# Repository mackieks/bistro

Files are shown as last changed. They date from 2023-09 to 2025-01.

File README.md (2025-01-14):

# bistro
Wii U regulator board. Runs a Wii U motherboard (no disc drive) from 1S lithium-ion. Licensed under Solderpad Hardware License v2.1. Have fun!

- x2 SiC431C 24A buck regulators for 1v and 1.15v (CPU + GPU)
- x2 MUN3CAD01-SB 1A bucks for 1.1V and 1.25V (for DRH)
- x1 MUN3CAD03-SE 3A buck for 1.5V (RAM)
- x1 TPS63810YFFR 2.5A buck-boost for 3.3V
- x1 FAN48610BUC50X 5V 1A boost (USB)

[Mouser project with BOM](https://www.mouser.com/ProjectManager/ProjectDetail.aspx?AccessID=d68b6111f5)

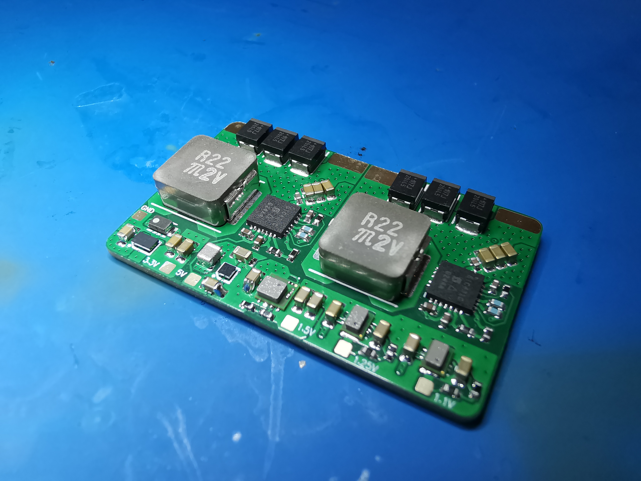
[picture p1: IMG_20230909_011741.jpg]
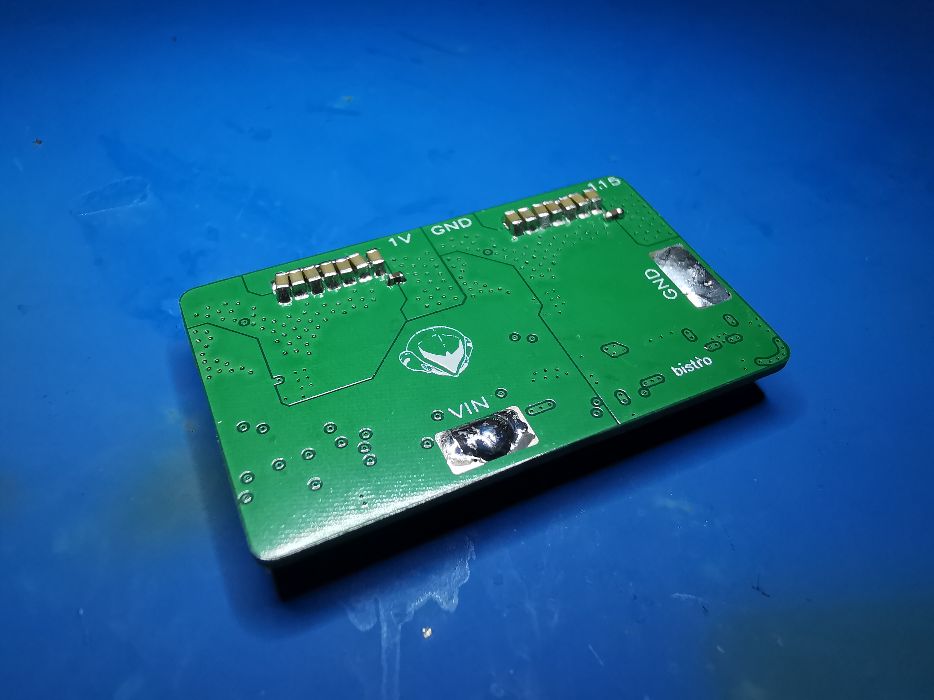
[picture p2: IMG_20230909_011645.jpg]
 


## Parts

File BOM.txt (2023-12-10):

Partlist

Exported from cafereg2.sch at 12/10/2023 4:18 PM

EAGLE Version 9.6.1 Copyright (c) 1988-2020 Autodesk, Inc.

Assembly variant: 

Part     Value                Device                   Package                 Library        Sheet

C1       22uF                 C-USC0603                C0603                   resistor       1
C2       22uF                 C-USC0603                C0603                   resistor       1
C3       22uF                 C-USC0603                C0603                   resistor       1
C4       0.1uF                C-USC0402                C0402                   resistor       1
C5       1uF                  C-USC0402                C0402                   resistor       1
C6       2.2uF                C-USC0402                C0402                   resistor       1
C7       0.1uF                C-USC0402                C0402                   resistor       1
C8       0.1uF                C-USC0402                C0402                   resistor       1
C9       22uF                 C-USC0603                C0603                   resistor       1
C10      22uF                 C-USC0603                C0603                   resistor       1
C11      22uF                 C-USC0603                C0603                   resistor       1
C12      22uF                 C-USC0603                C0603                   resistor       1
C13      22uF                 C-USC0603                C0603                   resistor       1
C14      22uF                 C-USC0603                C0603                   resistor       1
C15      22uF                 C-USC0603                C0603                   resistor       1
C16      0.1uF                C-USC0402                C0402                   resistor       1
C17      F930J107KBA          F930J107KBA              CAPPM3528X210N          SamacSys_Parts 1
C18      F930J107KBA          F930J107KBA              CAPPM3528X210N          SamacSys_Parts 1
C19      F930J107KBA          F930J107KBA              CAPPM3528X210N          SamacSys_Parts 1
C20      22uF                 C-USC0603                C0603                   resistor       2
C21      22uF                 C-USC0603                C0603                   resistor       2
C22      22uF                 C-USC0603                C0603                   resistor       2
C23      0.1uF                C-USC0402                C0402                   resistor       2
C24      1uF                  C-USC0402                C0402                   resistor       2
C25      2.2uF                C-USC0402                C0402                   resistor       2
C26      0.1uF                C-USC0402                C0402                   resistor       2
C27      0.1uF                C-USC0402                C0402                   resistor       2
C28      22uF                 C-USC0603                C0603                   resistor       2
C29      22uF                 C-USC0603                C0603                   resistor       2
C30      22uF                 C-USC0603                C0603                   resistor       2
C31      22uF                 C-USC0603                C0603                   resistor       2
C32      22uF                 C-USC0603                C0603                   resistor       2
C33      22uF                 C-USC0603                C0603                   resistor       2
C34      22uF                 C-USC0603                C0603                   resistor       2
C35      0.1uF                C-USC0402                C0402                   resistor       2
C36      F930J107KBA          F930J107KBA              CAPPM3528X210N          SamacSys_Parts 2
C37      F930J107KBA          F930J107KBA              CAPPM3528X210N          SamacSys_Parts 2
C38      F930J107KBA          F930J107KBA              CAPPM3528X210N          SamacSys_Parts 2
C39      22uF                 C-USC0603                C0603                   resistor       3
C40      22uF                 C-USC0603                C0603                   resistor       3
C41      22uF                 C-USC0603                C0603                   resistor       3
C42      22uF                 C-USC0603                C0603                   resistor       4
C43      22uF                 C-USC0603                C0603                   resistor       4
C44      22uF                 C-USC0603                C0603                   resistor       4
C45      22uF                 C-USC0603                C0603                   resistor       5
C46      22uF                 C-USC0603                C0603                   resistor       5
C47      22uF                 C-USC0603                C0603                   resistor       5
C48      22uF                 C-USC0603                C0603                   resistor       5
C49      22uF                 C-USC0603                C0603                   resistor       6
C50      22uF                 C-USC0603                C0603                   resistor       6
IC1      SiC431CED-T1-GE3     SiC431CED-T1-GE3         SiC431CED-T1-GE3        personal       1
IC2      SiC431CED-T1-GE3     SiC431CED-T1-GE3         SiC431CED-T1-GE3        personal       2
IC3      TPS63810YFFR         TPS63810YFFR             BGA15C40P3X5_134X226X62 SamacSys_Parts 3
IC4      MUN3CAD03-SE         MUN3CAD03-SE             MUN3CAD03SE             SamacSys_Parts 4
IC5      MUN3CAD01-SB         MUN3CAD01-SB             MUN3CAD01SB             SamacSys_Parts 5
IC6      MUN3CAD01-SB         MUN3CAD01-SB             MUN3CAD01SB             SamacSys_Parts 5
IC7      FAN48610BUC50X       FAN48610BUC50X           BGA9C40P3X3_122X122X62  SamacSys_Parts 6
L1       MPXV1D0840L1R0       MPXV1D0840L1R0           INDPM8680X400N          SamacSys_Parts 1
L2       MPXV1D0840L1R0       MPXV1D0840L1R0           INDPM8680X400N          SamacSys_Parts 2
L3       TFM201208BLE-R47MTCF L_CHIP-0805(2012-METRIC) INDC2009X120            Inductor       3
L4       1286AS-H-R47M=P2     1286AS-H-R47M=P2         1286ASH1R0MP2           SamacSys_Parts 6
R1       100k                 R-US_R0402               R0402                   resistor       1
R2       510k                 R-US_R0402               R0402                   resistor       1
R3       510k                 R-US_R0402               R0402                   resistor       1
R4       6.67k                R-US_R0402               R0402                   resistor       1
R5       10K                  R-US_R0402               R0402                   resistor       1
R6       100k                 R-US_R0402               R0402                   resistor       2
R7       510k                 R-US_R0402               R0402                   resistor       2
R8       510k                 R-US_R0402               R0402                   resistor       2
R9       11k                  R-US_R0402               R0402                   resistor       2
R10      12k                  R-US_R0402               R0402                   resistor       2
R11      200k                 R-US_R0402               R0402                   resistor       4
R12      133k                 R-US_R0402               R0402                   resistor       4
R13      200k                 R-US_R0402               R0402                   resistor       5
R14      187k                 R-US_R0402               R0402                   resistor       5
R15      187k                 R-US_R0402               R0402                   resistor       5
R16      200k                 R-US_R0402               R0402                   resistor       5

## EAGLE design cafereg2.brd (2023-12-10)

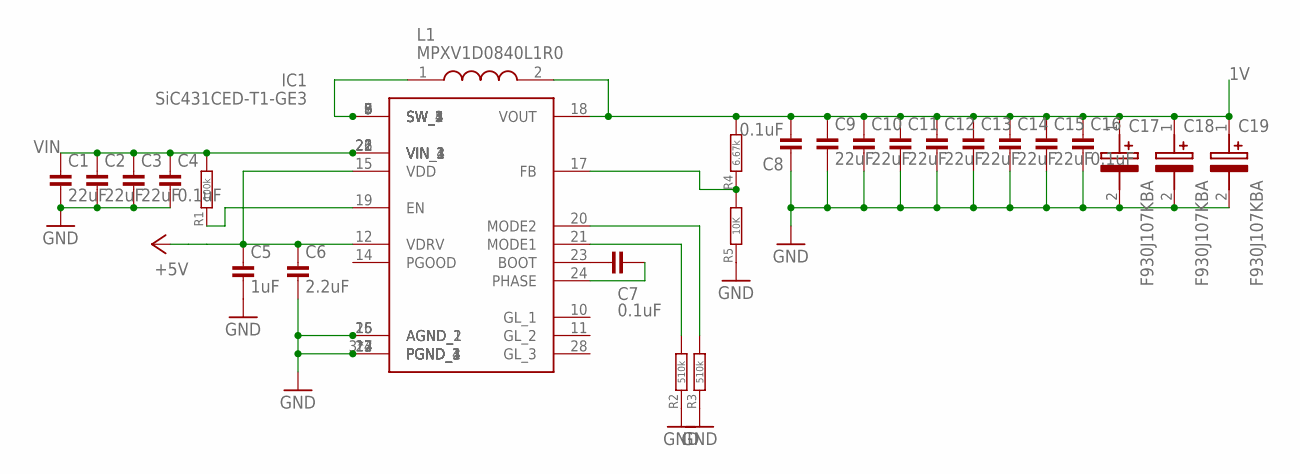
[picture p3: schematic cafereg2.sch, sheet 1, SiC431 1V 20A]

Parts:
C1, C2, C3, C9, C10, C11, C12, C13, C14, C15: 22uF; C0603
C4, C7, C8, C16: 0.1uF; C0402
C5: 1uF; C0402
C6: 2.2uF; C0402
C17, C18, C19: F930J107KBA; CAPPM3528X210N
IC1: SiC431CED-T1-GE3; SIC431AEDT1GE3
L1: MPXV1D0840L1R0; INDPM8680X400N
R1: 100k; R0402
R2, R3: 510k; R0402
R4: 6.67k; R0402
R5: 10K; R0402

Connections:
1V: C8.2, C9.1, C10.1, C11.1, C12.1, C13.1, C14.1, C15.1, C16.1, C17.1 (+), C18.1 (+), C19.1 (+), IC1.18 (VOUT), L1.2, R4.2
+5V: C5.1, C6.1, IC1.12 (VDRV), IC1.15 (VDD); also elsewhere on the board
BOOT: C7.1, IC1.23 (BOOT)
FB: IC1.17 (FB), R4.1, R5.2
GND: C1.2, C2.2, C3.2, C4.2, C5.2, C6.2, C8.1, C9.2, C10.2, C11.2, C12.2, C13.2, C14.2, C15.2, C16.2, C17.2 (-), C18.2 (-), C19.2 (-), IC1.3 (PGND_1), IC1.4 (PGND_2), IC1.13 (PGND_3), IC1.16 (AGND_1), IC1.25 (AGND_2), IC1.27 (PGND_4), IC1.29 (PGND_1), R2.1, R3.1, R5.1; also elsewhere on the board
unnamed: IC1.19 (EN), R1.1
unnamed: IC1.21 (MODE1), R2.2
unnamed: IC1.5 (SW_1), IC1.6 (SW_2), IC1.7 (SW_3), IC1.8 (SW_4), IC1.9 (SW_5), L1.1
unnamed: IC1.20 (MODE2), R3.2
PHASE: C7.2, IC1.24 (PHASE)
VIN: C1.1, C2.1, C3.1, C4.1, IC1.1 (VIN_1), IC1.2 (VIN_2), IC1.22 (VIN_3), IC1.26 (VIN_4), R1.2; also elsewhere on the board

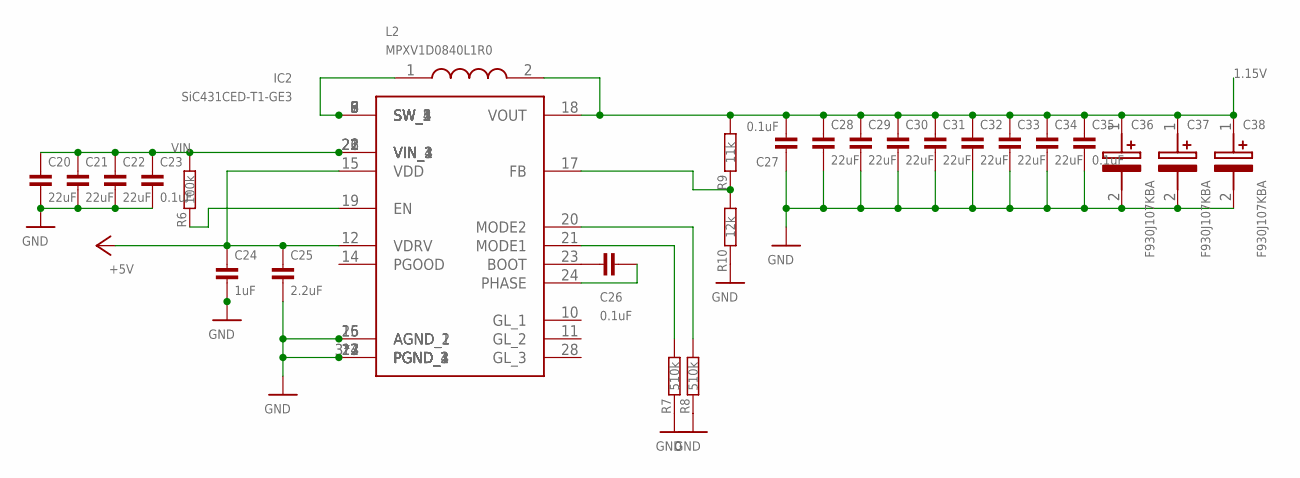
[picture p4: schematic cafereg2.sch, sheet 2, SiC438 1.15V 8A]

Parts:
C20, C21, C22, C28, C29, C30, C31, C32, C33, C34: 22uF; C0603
C23, C26, C27, C35: 0.1uF; C0402
C24: 1uF; C0402
C25: 2.2uF; C0402
C36, C37, C38: F930J107KBA; CAPPM3528X210N
IC2: SiC431CED-T1-GE3; SIC431AEDT1GE3
L2: MPXV1D0840L1R0; INDPM8680X400N
R6: 100k; R0402
R7, R8: 510k; R0402
R9: 11k; R0402
R10: 12k; R0402

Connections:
1.15V: C27.2, C28.1, C29.1, C30.1, C31.1, C32.1, C33.1, C34.1, C35.1, C36.1 (+), C37.1 (+), C38.1 (+), IC2.18 (VOUT), L2.2, R9.2
+5V: C24.1, C25.1, IC2.12 (VDRV), IC2.15 (VDD); also elsewhere on the board
BOOT2: C26.1, IC2.23 (BOOT)
FB2: IC2.17 (FB), R9.1, R10.2
GND: C20.2, C21.2, C22.2, C23.2, C24.2, C25.2, C27.1, C28.2, C29.2, C30.2, C31.2, C32.2, C33.2, C34.2, C35.2, C36.2 (-), C37.2 (-), C38.2 (-), IC2.3 (PGND_1), IC2.4 (PGND_2), IC2.13 (PGND_3), IC2.16 (AGND_1), IC2.25 (AGND_2), IC2.27 (PGND_4), IC2.29 (PGND_1), R7.1, R8.1, R10.1; also elsewhere on the board
unnamed: IC2.19 (EN), R6.1
unnamed: IC2.5 (SW_1), IC2.6 (SW_2), IC2.7 (SW_3), IC2.8 (SW_4), IC2.9 (SW_5), L2.1
unnamed: IC2.21 (MODE1), R7.2
unnamed: IC2.20 (MODE2), R8.2
PHASE2: C26.2, IC2.24 (PHASE)
VIN: C20.1, C21.1, C22.1, C23.1, IC2.1 (VIN_1), IC2.2 (VIN_2), IC2.22 (VIN_3), IC2.26 (VIN_4), R6.2; also elsewhere on the board

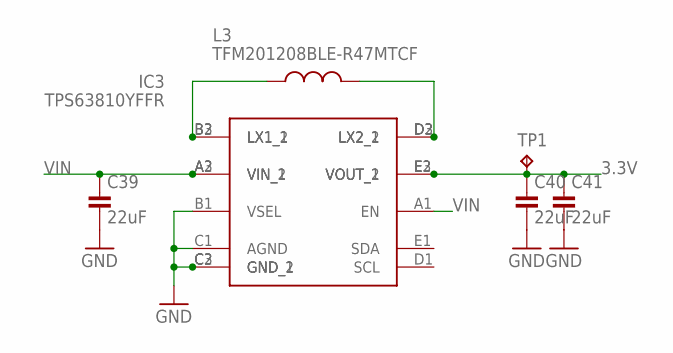
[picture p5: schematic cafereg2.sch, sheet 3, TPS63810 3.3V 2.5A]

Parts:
C39, C40, C41: 22uF; C0603
IC3: TPS63810YFFR; BGA15C40P3X5_134X226X62
L3: TFM201208BLE-R47MTCF; INDC2009X120
TP1: TPTP12SQ; TP12SQ

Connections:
3.3V: C40.1, C41.1, IC3.E2 (VOUT_1), IC3.E3 (VOUT_2), TP1.TP
GND: C39.2, C40.2, C41.2, IC3.B1 (VSEL), IC3.C1 (AGND), IC3.C2 (GND_1), IC3.C3 (GND_2); also elsewhere on the board
SW1: IC3.B2 (LX1_1), IC3.B3 (LX1_2), L3.1
SW2: IC3.D2 (LX2_1), IC3.D3 (LX2_2), L3.2
VIN: C39.1, IC3.A1 (EN), IC3.A2 (VIN_1), IC3.A3 (VIN_2); also elsewhere on the board

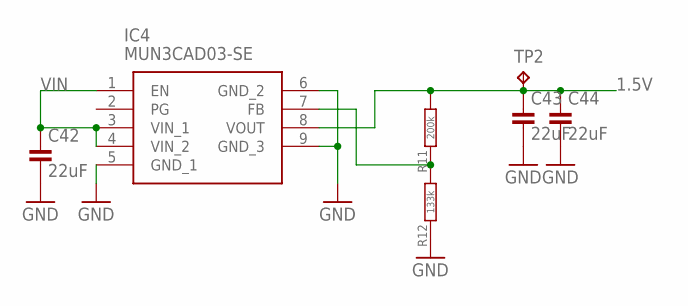
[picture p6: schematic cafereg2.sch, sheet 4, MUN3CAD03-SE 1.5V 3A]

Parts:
C42, C43, C44: 22uF; C0603
IC4: MUN3CAD03-SE; MUN3CAD03SE
R11: 200k; R0402
R12: 133k; R0402
TP2: TPTP12SQ; TP12SQ

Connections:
1.5V: C43.1, C44.1, IC4.8 (VOUT), R11.2, TP2.TP
FB1: IC4.7 (FB), R11.1, R12.2
GND: C42.2, C43.2, C44.2, IC4.5 (GND_1), IC4.6 (GND_2), IC4.9 (GND_3), R12.1; also elsewhere on the board
VIN: C42.1, IC4.1 (EN), IC4.3 (VIN_1), IC4.4 (VIN_2); also elsewhere on the board

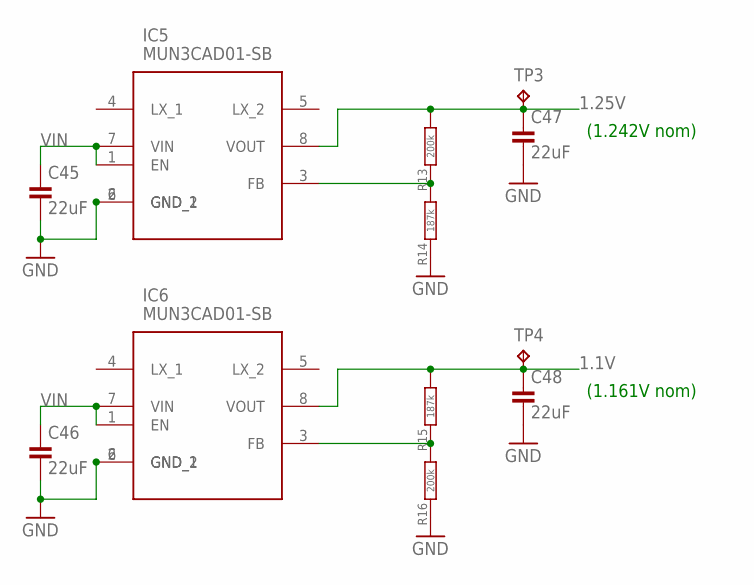
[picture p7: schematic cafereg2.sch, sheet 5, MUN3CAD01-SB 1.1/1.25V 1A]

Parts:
C45, C46, C47, C48: 22uF; C0603
IC5, IC6: MUN3CAD01-SB; MUN3CAD01SB
R13, R16: 200k; R0402
R14, R15: 187k; R0402
TP3, TP4: TPTP12SQ; TP12SQ

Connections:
1.1V: C48.1, IC6.8 (VOUT), R15.2, TP4.TP
1.25V: C47.1, IC5.8 (VOUT), R13.2, TP3.TP
GND: C45.2, C46.2, C47.2, C48.2, IC5.2 (GND_1), IC5.6 (GND_2), IC6.2 (GND_1), IC6.6 (GND_2), R14.1, R16.1; also elsewhere on the board
unnamed: IC6.3 (FB), R15.1, R16.2
unnamed: IC5.3 (FB), R13.1, R14.2
VIN: C45.1, C46.1, IC5.1 (EN), IC5.7 (VIN), IC6.1 (EN), IC6.7 (VIN); also elsewhere on the board

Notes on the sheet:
(1.161V nom)
(1.242V nom)

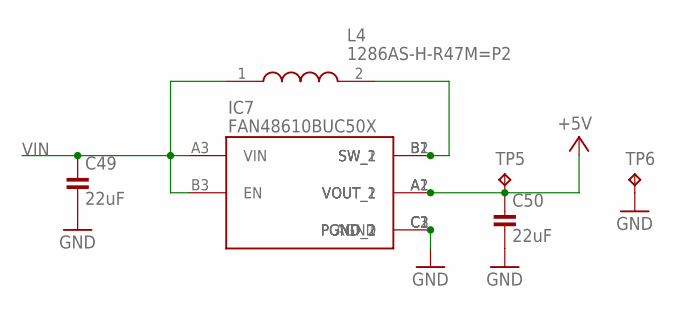
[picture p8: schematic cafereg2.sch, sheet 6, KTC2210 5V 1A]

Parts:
C49, C50: 22uF; C0603
IC7: FAN48610BUC50X; BGA9C40P3X3_122X122X62
L4: 1286AS-H-R47M=P2; 1286ASH1R0MP2
TP5, TP6: TPTP12SQ; TP12SQ

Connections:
+5V: C50.1, IC7.A1 (VOUT_1), IC7.A2 (VOUT_2), TP5.TP; also elsewhere on the board
GND: C49.2, C50.2, IC7.C1 (PGND_1), IC7.C2 (PGND_2), IC7.C3 (AGND), TP6.TP; also elsewhere on the board
SW: IC7.B1 (SW_1), IC7.B2 (SW_2), L4.2
VIN: C49.1, IC7.A3 (VIN), IC7.B3 (EN), L4.1; also elsewhere on the board

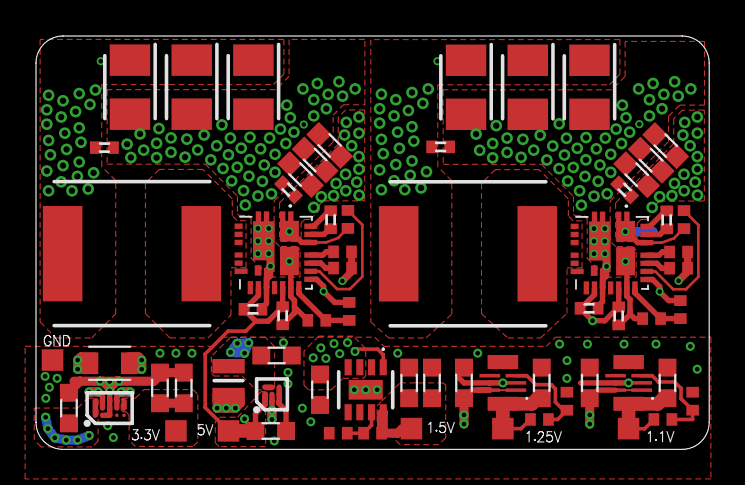
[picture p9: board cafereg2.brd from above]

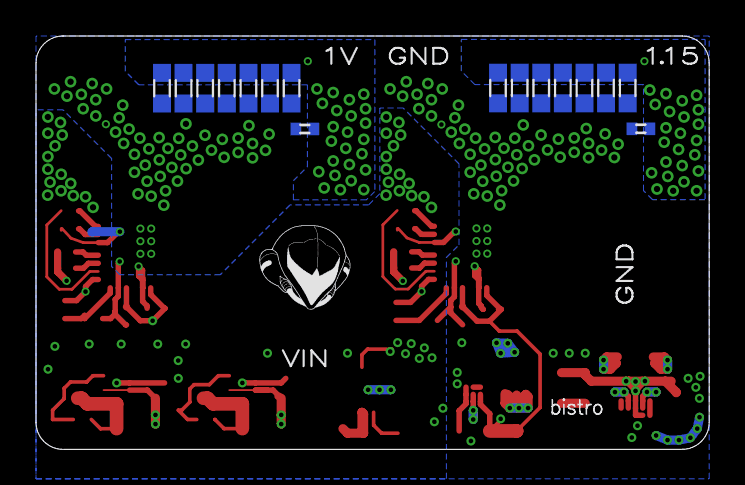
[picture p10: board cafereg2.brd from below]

Board: 4 copper layers, 37.4 x 23.0 mm, 83 parts (16 on the bottom side), 29 nets.

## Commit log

2023-09-17 add board pics
2023-12-10 update bom
    [cafereg2.brd, cafereg2.sch]
2024-01-23 change to solderpad license
